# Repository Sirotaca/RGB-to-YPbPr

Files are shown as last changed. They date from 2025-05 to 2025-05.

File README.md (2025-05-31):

# RGB to YPbPr Converter
This board accepts RGBHV or RGBS with any sync polarity via a DE-15 (VGA) input and converts it into YPbPr component video. Video timing is unchanged, so ensure that your display or video processor is compatible with the resolution of the source. The transformation matrix uses Rec. 601 coefficients, so resolutions higher than 480p will have slightly incorrect colors.

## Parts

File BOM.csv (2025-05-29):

Reference | Value | Datasheet | Footprint | Qty | DNP
C1,C2,C3 | 100u | ~ | Capacitor_THT:CP_Radial_D6.3mm_P2.50mm | 3
C4,C5,C13,C14,C15,C16,C17,C19,C20 | 1u | ~ | Capacitor_SMD:C_0805_2012Metric_Pad1.18x1.45mm_HandSolder | 9
C6,C8,C9,C10,C11,C12,C18,C21 | 0.1u | ~ | Capacitor_SMD:C_0805_2012Metric_Pad1.18x1.45mm_HandSolder | 8
C7 | 10u | ~ | Capacitor_SMD:C_0805_2012Metric_Pad1.18x1.45mm_HandSolder | 1
D1 | WP934CB/ID | ~ | retro_gaming:WP934 | 1
J1 | Pr | ~ | retro_gaming:CUI_RCJ-04x | 1
J2 | Pb | ~ | retro_gaming:CUI_RCJ-04x | 1
J3 | Y | ~ | retro_gaming:CUI_RCJ-04x | 1
J4 | DB15_Female_HighDensity_MountingHoles | ~ | retro_gaming:AMPHENOL_L17HTHES4F1C | 1
J5 | USB_C_Receptacle_Power_Only | https://www.usb.org/sites/default/files/documents/usb_type-c.zip | Connector_USB:USB_C_Receptacle_GCT_USB4125-xx-x-0190_6P_TopMnt_Horizontal | 1
L1 | 1k @ 100 kHz | ~ | Inductor_SMD:L_0805_2012Metric_Pad1.15x1.40mm_HandSolder | 1
R1,R5,R11,R21,R24,R25 | 75 | ~ | Resistor_SMD:R_0805_2012Metric_Pad1.20x1.40mm_HandSolder | 6
R2 | 1.07k | ~ | Resistor_SMD:R_0805_2012Metric_Pad1.20x1.40mm_HandSolder | 1
R3 | 2.94k | ~ | Resistor_SMD:R_0805_2012Metric_Pad1.20x1.40mm_HandSolder | 1
R4 | 549 | ~ | Resistor_SMD:R_0805_2012Metric_Pad1.20x1.40mm_HandSolder | 1
R6,R12,R17 | 560 | ~ | Resistor_SMD:R_0805_2012Metric_Pad1.20x1.40mm_HandSolder | 3
R7 | 1.65k | ~ | Resistor_SMD:R_0805_2012Metric_Pad1.20x1.40mm_HandSolder | 1
R8 | 845 | ~ | Resistor_SMD:R_0805_2012Metric_Pad1.20x1.40mm_HandSolder | 1
R9,R10,R15,R16,R30 | 1k | ~ | Resistor_SMD:R_0805_2012Metric_Pad1.20x1.40mm_HandSolder | 5
R13 | 665 | ~ | Resistor_SMD:R_0805_2012Metric_Pad1.20x1.40mm_HandSolder | 1
R14 | 3.48k | ~ | Resistor_SMD:R_0805_2012Metric_Pad1.20x1.40mm_HandSolder | 1
R18,R22,R23 | 100k | ~ | Resistor_SMD:R_0805_2012Metric_Pad1.20x1.40mm_HandSolder | 3
R19 | 634 | ~ | Resistor_SMD:R_0805_2012Metric_Pad1.20x1.40mm_HandSolder | 1
R20 | 4.64k | ~ | Resistor_SMD:R_0805_2012Metric_Pad1.20x1.40mm_HandSolder | 1
R26,R27 | 2.2k | ~ | Resistor_SMD:R_0805_2012Metric_Pad1.20x1.40mm_HandSolder | 2
R28,R29 | 10k | ~ | Resistor_SMD:R_0805_2012Metric_Pad1.20x1.40mm_HandSolder | 2
R31,R32 | 5.1k | ~ | Resistor_SMD:R_0805_2012Metric_Pad1.20x1.40mm_HandSolder | 2
U1 | MIC5365-3.0YD5 | http://ww1.microchip.com/downloads/en/DeviceDoc/mic5365.pdf | Package_TO_SOT_SMD:TSOT-23-5 | 1
U2,U3,U4 | LMH6612 | ~ | Package_SO:SOIC-8_3.9x4.9mm_P1.27mm | 3
U5 | MIC5270-3.0YM5 | MIC5270-3.0YM5-TR | Package_TO_SOT_SMD:SOT-23-5 | 1
U6 | LM2660 | https://www.analog.com/media/en/technical-documentation/data-sheets/660fa.pdf | Package_SO:SOIC-8_3.9x4.9mm_P1.27mm | 1
U7 | 74HCT86 | 74xx/74ls86.pdf | Package_SO:SOIC-14_3.9x8.7mm_P1.27mm | 1

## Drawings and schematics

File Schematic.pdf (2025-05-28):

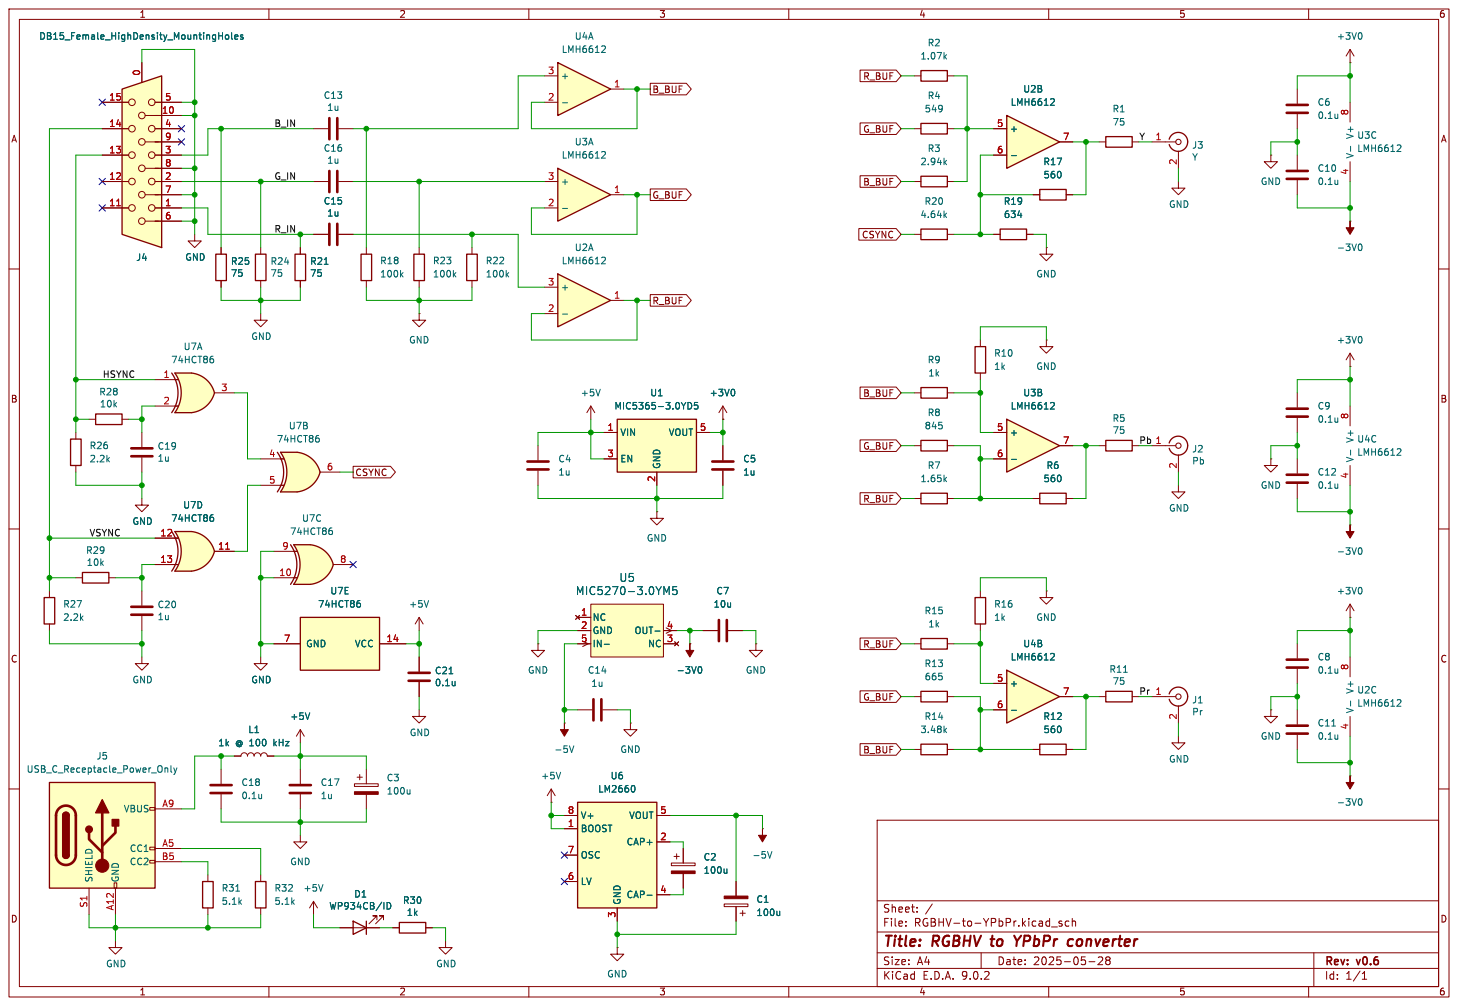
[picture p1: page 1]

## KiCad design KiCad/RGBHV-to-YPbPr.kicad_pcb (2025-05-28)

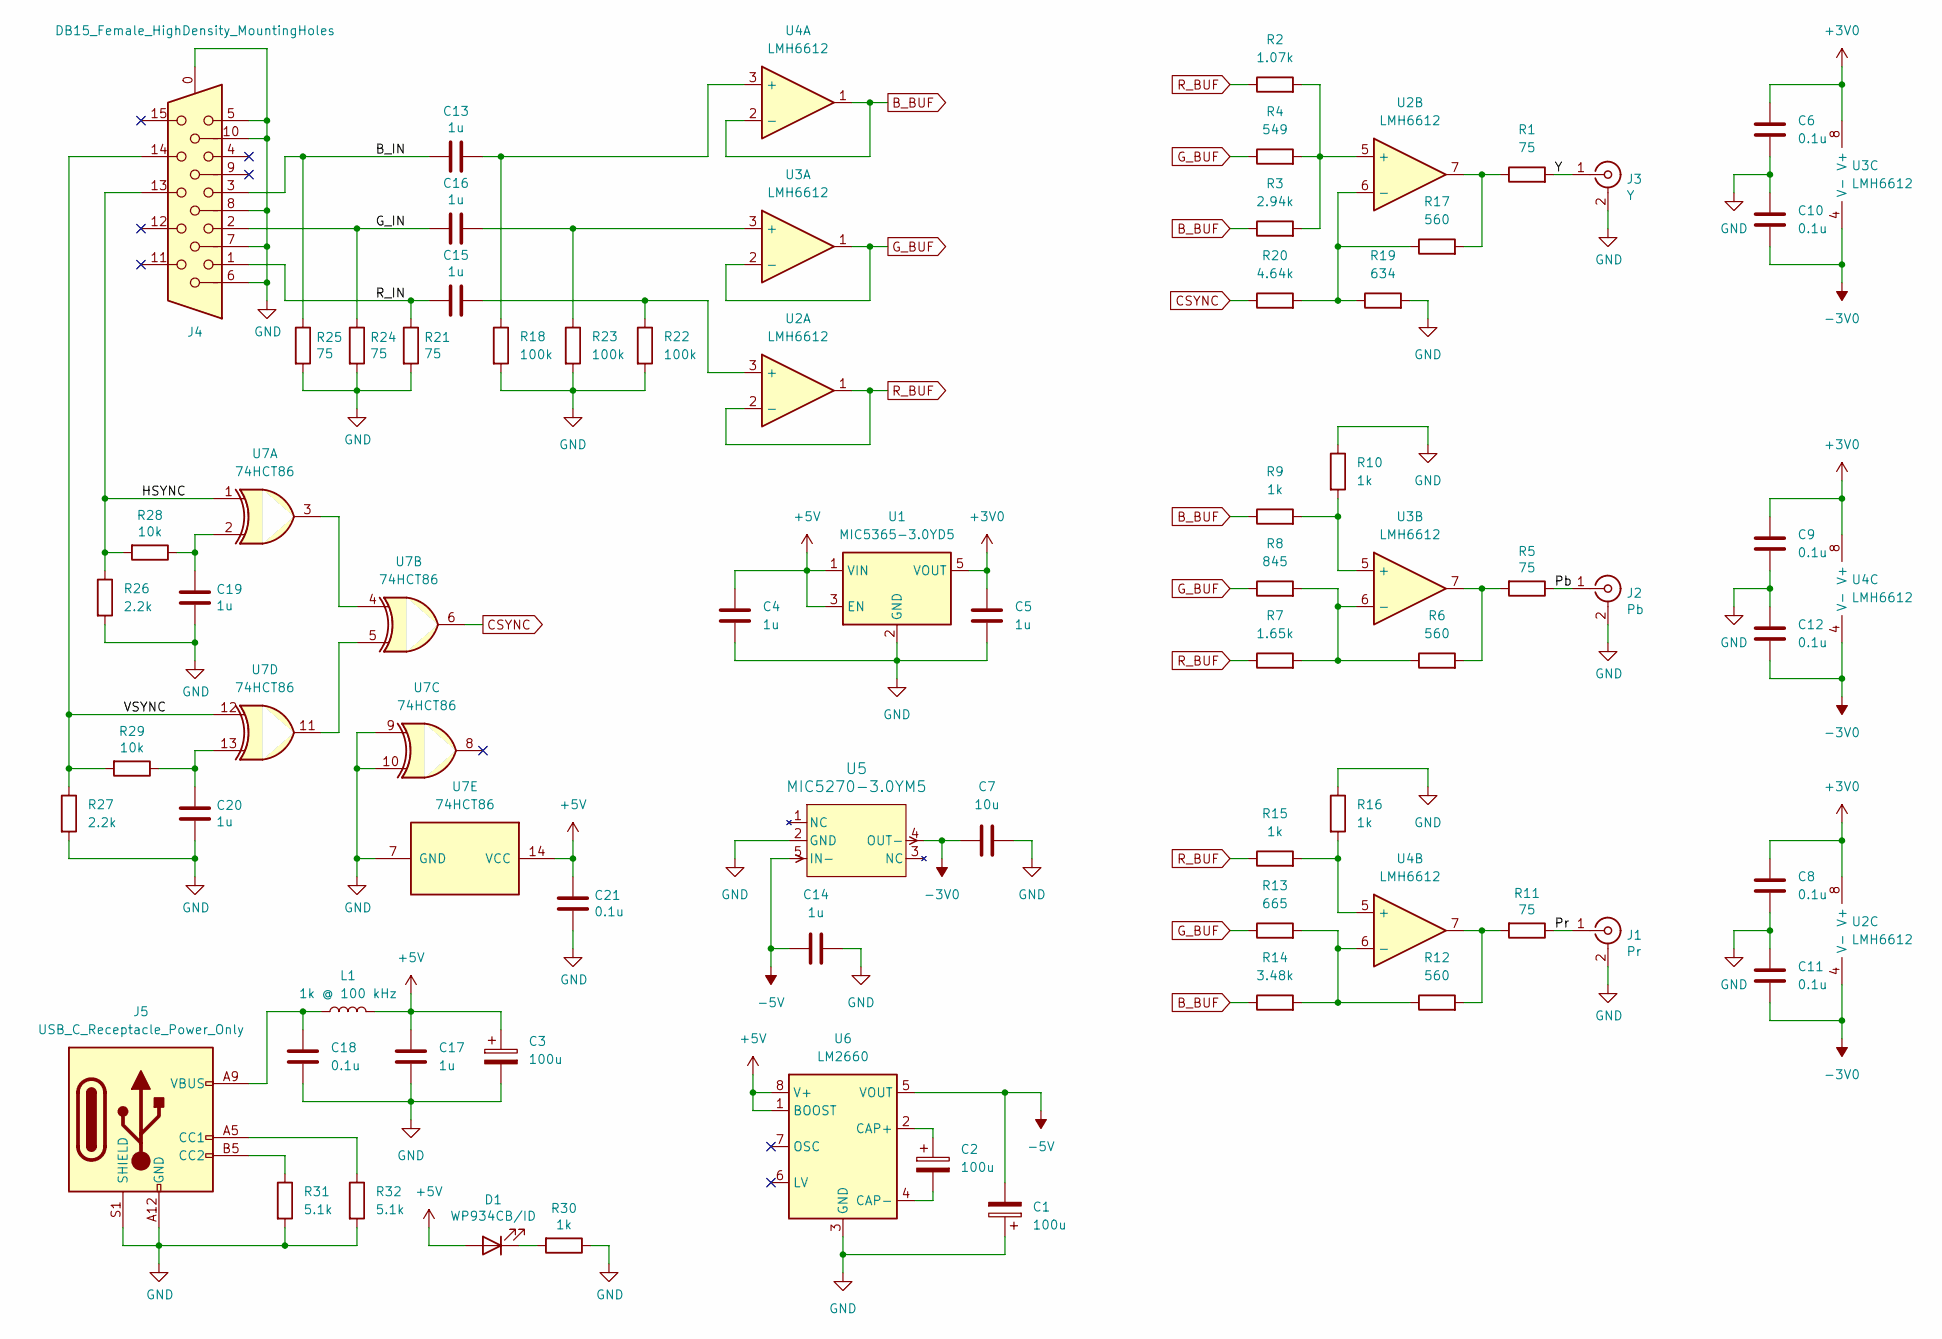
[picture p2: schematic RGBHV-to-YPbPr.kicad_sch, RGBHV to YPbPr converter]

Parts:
C1, C2, C3: 100u; CP_Radial_D6.3mm_P2.50mm
C4, C5, C13, C14, C15, C16, C17, C19, C20: 1u; C_0805_2012Metric_Pad1.18x1.45mm_HandSolder
C6, C8, C9, C10, C11, C12, C18, C21: 0.1u; C_0805_2012Metric_Pad1.18x1.45mm_HandSolder
C7: 10u; C_0805_2012Metric_Pad1.18x1.45mm_HandSolder
D1: WP934CB/ID; WP934
J1: Pr; CUI_RCJ-04x
J2: Pb; CUI_RCJ-04x
J3: Y; CUI_RCJ-04x
J4: DB15_Female_HighDensity_MountingHoles; AMPHENOL_L17HTHES4F1C
J5: USB_C_Receptacle_Power_Only; USB_C_Receptacle_GCT_USB4125-xx-x-0190_6P_TopMnt_Horizontal
L1: 1k @ 100 kHz; L_0805_2012Metric_Pad1.15x1.40mm_HandSolder
R1, R5, R11, R21, R24, R25: 75; R_0805_2012Metric_Pad1.20x1.40mm_HandSolder
R2: 1.07k; R_0805_2012Metric_Pad1.20x1.40mm_HandSolder
R3: 2.94k; R_0805_2012Metric_Pad1.20x1.40mm_HandSolder
R4: 549; R_0805_2012Metric_Pad1.20x1.40mm_HandSolder
R6, R12, R17: 560; R_0805_2012Metric_Pad1.20x1.40mm_HandSolder
R7: 1.65k; R_0805_2012Metric_Pad1.20x1.40mm_HandSolder
R8: 845; R_0805_2012Metric_Pad1.20x1.40mm_HandSolder
R9, R10, R15, R16, R30: 1k; R_0805_2012Metric_Pad1.20x1.40mm_HandSolder
R13: 665; R_0805_2012Metric_Pad1.20x1.40mm_HandSolder
R14: 3.48k; R_0805_2012Metric_Pad1.20x1.40mm_HandSolder
R18, R22, R23: 100k; R_0805_2012Metric_Pad1.20x1.40mm_HandSolder
R19: 634; R_0805_2012Metric_Pad1.20x1.40mm_HandSolder
R20: 4.64k; R_0805_2012Metric_Pad1.20x1.40mm_HandSolder
R26, R27: 2.2k; R_0805_2012Metric_Pad1.20x1.40mm_HandSolder
R28, R29: 10k; R_0805_2012Metric_Pad1.20x1.40mm_HandSolder
R31, R32: 5.1k; R_0805_2012Metric_Pad1.20x1.40mm_HandSolder
U1: MIC5365-3.0YD5; TSOT-23-5
U2, U3, U4: LMH6612; SOIC-8_3.9x4.9mm_P1.27mm
U5: MIC5270-3.0YM5; SOT-23-5
U6: LM2660; SOIC-8_3.9x4.9mm_P1.27mm
U7: 74HCT86; SOIC-14_3.9x8.7mm_P1.27mm

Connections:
+3V0: C5.1, C6.1, C8.1, C9.1, U1.5 (VOUT), U2.8 (V+), U3.8 (V+), U4.8 (V+)
+5V: C3.1, C4.1, C17.1, C21.1, D1.2 (A), L1.2, U1.1 (VIN), U1.3 (EN), U6.1 (BOOST), U6.8 (V+), U7.14 (VCC)
-3V0: C7.1, C10.2, C11.2, C12.2, U2.4 (V-), U3.4 (V-), U4.4 (V-), U5.4 (OUT-)
-5V: C1.2, C14.1, U5.5 (IN-), U6.5 (VOUT)
/B_IN: C13.2, J4.3, R25.1
/G_IN: C16.2, J4.2, R24.1
/HSYNC: J4.13, R26.1, R28.2, U7.1
/Pb: J2.1 (In), R5.1
/Pr: J1.1 (In), R11.1
/R_IN: C15.2, J4.1, R21.1
/VSYNC: J4.14, R27.1, R29.2, U7.12
/Y: J3.1 (In), R1.2
B_BUF: R3.1, R9.1, R14.1, U4.1, U4.2 (-)
CSYNC: R20.1, U7.6
GND: C1.1, C3.2, C4.2, C5.2, C6.2, C7.2, C8.2, C9.2, C10.1, C11.1, C12.1, C14.2, C17.2, C18.2, C19.2, C20.2, C21.2, J1.2 (Ext), J2.2 (Ext), J3.2 (Ext), J4.0, J4.5, J4.6, J4.7, J4.8, J4.10, J4.SH1, J4.SH2, J5.A12 (GND), J5.B12 (GND), J5.S1 (SHIELD), R10.1, R16.1, R18.2, R19.2, R21.2, R22.2, R23.2, R24.2, R25.2, R26.2, R27.2, R30.1, R31.2, R32.2, U1.2 (GND), U5.2 (GND), U6.3 (GND), U7.7 (GND), U7.9, U7.10
G_BUF: R4.1, R8.1, R13.1, U3.1, U3.2 (-)
unnamed: C18.1, J5.A9 (VBUS), J5.B9 (VBUS), L1.1
unnamed: C19.1, R28.1, U7.2
unnamed: C20.1, R29.1, U7.13
unnamed: D1.1 (K), R30.2
unnamed: J5.A5 (CC1), R32.1
unnamed: J5.B5 (CC2), R31.1
unnamed: R1.1, R17.2, U2.7
unnamed: R5.2, R6.2, U3.7
unnamed: R11.2, R12.2, U4.7
unnamed: C15.1, R22.1, U2.3 (+)
unnamed: R2.2, R3.2, R4.2, U2.5 (+)
unnamed: R17.1, R19.1, R20.2, U2.6 (-)
unnamed: C16.1, R23.1, U3.3 (+)
unnamed: R9.2, R10.2, U3.5 (+)
unnamed: R6.1, R7.2, R8.2, U3.6 (-)
unnamed: C13.1, R18.1, U4.3 (+)
unnamed: R15.2, R16.2, U4.5 (+)
unnamed: R12.1, R13.2, R14.2, U4.6 (-)
unnamed: C2.1, U6.2 (CAP+)
unnamed: C2.2, U6.4 (CAP-)
unnamed: U7.3, U7.4
unnamed: U7.5, U7.11
R_BUF: R2.1, R7.1, R15.1, U2.1, U2.2 (-)

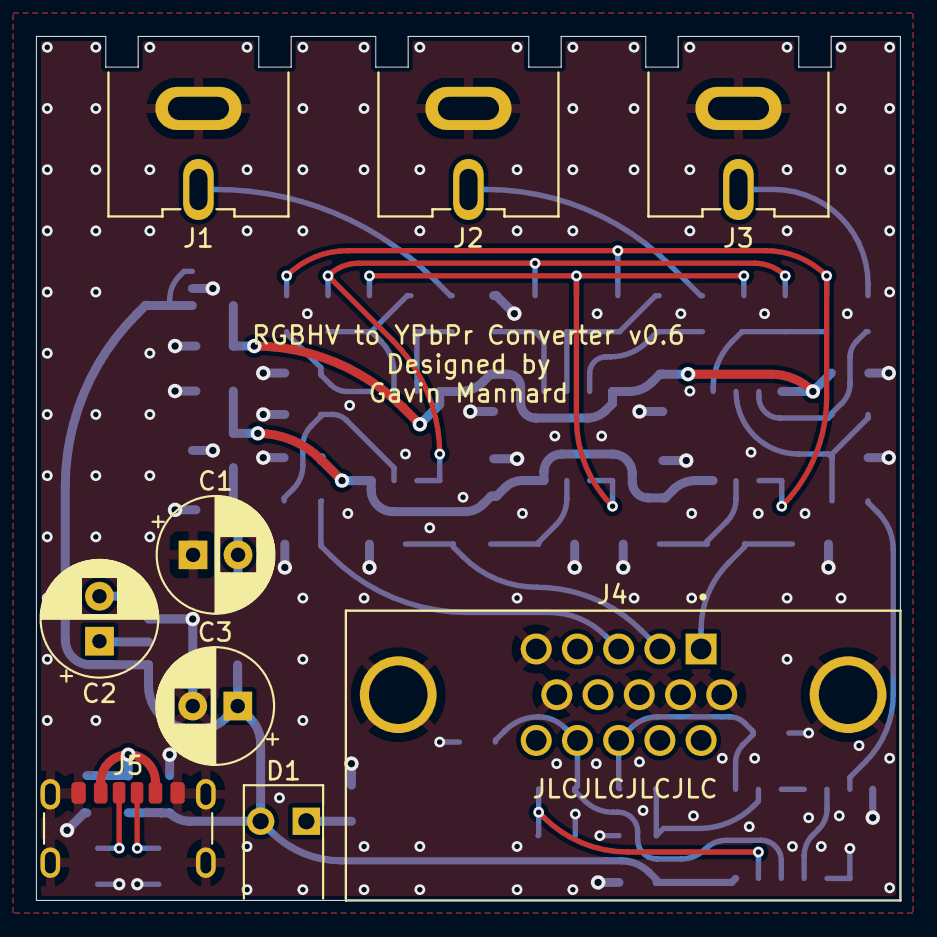
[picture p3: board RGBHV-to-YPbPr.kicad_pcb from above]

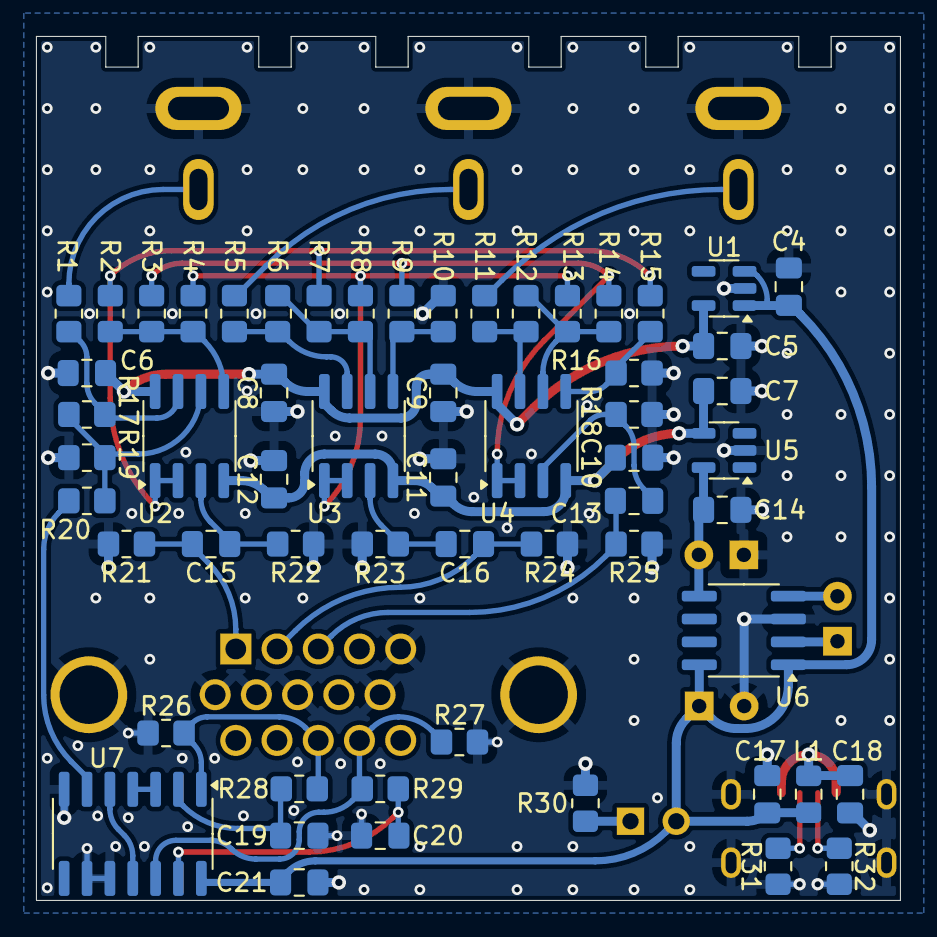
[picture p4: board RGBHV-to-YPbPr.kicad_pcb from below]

Board: 2 copper layers, 48.0 x 48.0 mm, 67 parts (58 on the bottom side), 39 nets.
